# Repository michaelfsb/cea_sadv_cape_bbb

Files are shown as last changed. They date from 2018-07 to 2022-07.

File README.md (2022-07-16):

# cea_sadv_cape_bbb
Projeto no KiCad de um módulo para aquisição dados em voo realizado no projeto de Iniciação Cientifica intitulado "Modernização do Sistema de Aquisição de Dados de Voo do CEA".

cape

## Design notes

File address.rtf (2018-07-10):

I2C_2

MPU9250
68h (0)
69h (1)

4525DO - I2C_2
Definido na compra (olhar no nome)
28h, 36h, 46h, 48h ... 51h

DS3231
57h (não achei essa inf no datasheet)

CAT24C256
54h to 57h (segundo manual beaglebone)
1010 XXX Y (X - são progamaveis Y - leitura ou escrita)

I2C_1

MPU6050
68h (0)
69h (1)

BMP180
EFh (read) and EEh (write)

HMC5883
3Dh (read) and 3Ch (write)

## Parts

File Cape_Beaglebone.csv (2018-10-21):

Id | Designator | Package | Quantity | Designation | Supplier and ref
1 | NT2,NT1 | net_tie2 | 2 | Net-Tie_2
2 | C34,C33,C10,C11,C12,C13 | C_0805 | 6 | C
3 | L2,L1 | R_Axial_DIN0204_L3.6mm_D1.6mm_P7.62mm_Horizontal | 2 | I
4 | P8,P9 | Socket_BeagleBone_Black | 2 | BeagleBone_Black_Header
5 | R17,R18 | R_0603 | 2 | 0
6 | IC9 | PQFN50P300X300X100-16N | 1 | LSM303D
7 | IC10 | 16-PIN-LPCC | 1 | HMC5883L-TR
8 | IC5 | SOIC127P800X203-8N | 1 | CAT24C256WI-GT3
9 | IC11 | BMP180 | 1 | BMP180
10 | IC4,IC2 | SOIC127P600X160-16N | 2 | HX711
11 | IC6,IC7 | SOP65P640X120-16N | 2 | AD7793BRUZ
12 | IC12 | SOP50P640X120-38N | 1 | ADS8688IDBT
13 | IC13 | LGA(3X3X1.0-16L) | 1 | L3GD20H
14 | IC8 | QFN40P300X300X95-25N-D | 1 | MPU-6500
15 | IC3 | SOIC127P1032X265-16N | 1 | DS3231S
16 | U1 | 4525DO-DS...P | 1 | 4525DO-DS5AI001DP
17 | J5 | test_pad | 1 | M_WP
18 | SW1 | SW_DIP_x2_W5.08mm_Slide_Copal_CHS-A | 1 | SW_DIP_x02
19 | C24,C9 | C_0805 | 2 | 22u
20 | J11,J4,J6,J16 | JST_SH_BM06B-SRSS-TB_06x1.00mm_Straight | 4 | Conn_01x06
21 | J3 | JST_SH_BM02B-SRSS-TB_02x1.00mm_Straight | 1 | Conn_01x02
22 | J1,J2,J7,J8,J9,J10,J12,J13,J14,J15 | JST_SH_BM04B-SRSS-TB_04x1.00mm_Straight | 10 | Conn_01x04
23 | C1,C6,C18,C25,C29,C32 | C_0805 | 6 | 10u
24 | C2,C14,C31 | C_0805 | 3 | 10n
25 | C3,C4,C5,C7,C8,C15,C16,C19 | C_0805 | 8 | 0.1u
26 | C17,C27 | C_0805 | 2 | 4.7u
27 | C20,C26,C30 | C_0805 | 3 | 1u
28 | C21 | C_0805 | 1 | 0.22u
29 | C22,C23,C28 | C_0805 | 3 | 100n
30 | IC1 | QFN40P300X300X105-25N-D | 1 | MPU-9250
31 | Q1,Q2 | SOT-23 | 2 | BC807
32 | R1,R2,R3,R4,R5,R6,R13,R14 | R_0603 | 8 | R
33 | R7,R8,R9 | R_0603 | 3 | 4.7k
34 | R10,R11,R12,R15,R16 | R_0603 | 5 | 10k
35 | G*** | LOGO | 1 | LOGO

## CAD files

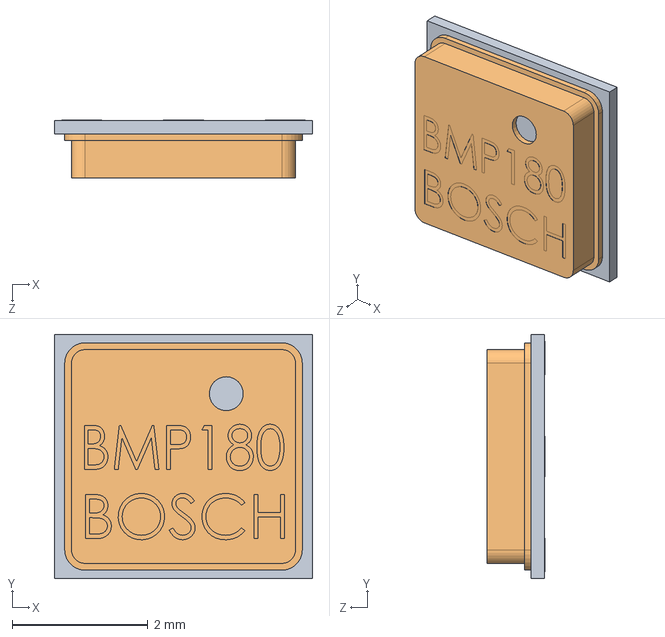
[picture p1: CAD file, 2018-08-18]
componetes/BMP180/bmp180-2.snapshot.1/BMP_180/BMP180.SLDASM
3.80 x 3.60 x 0.856 mm
PCB
Cover

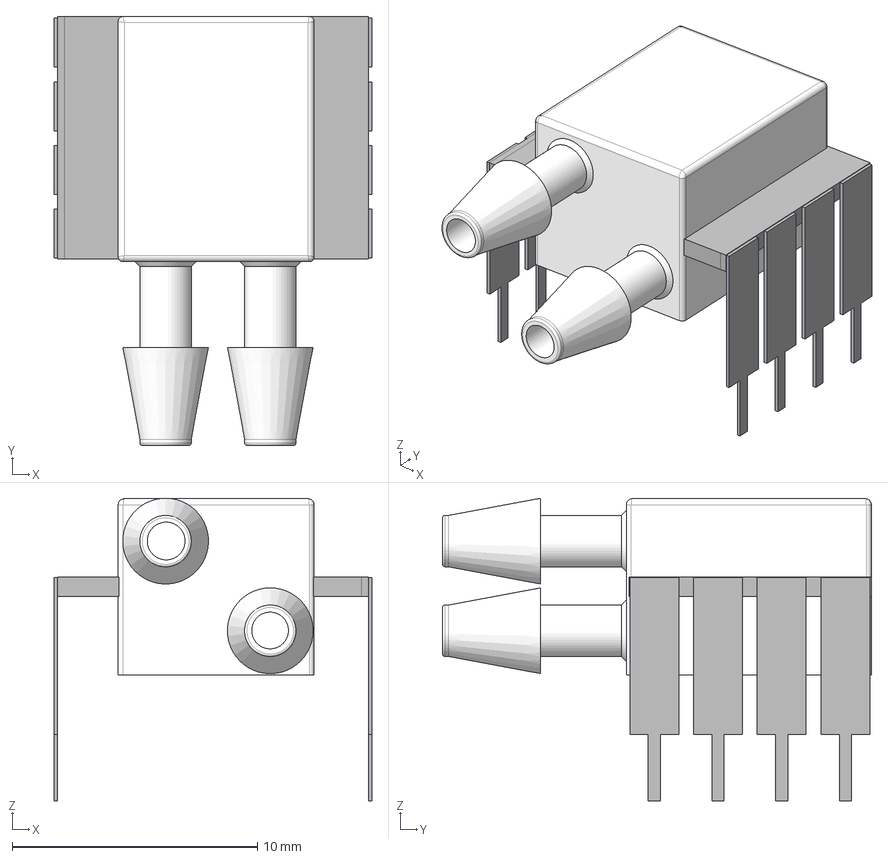
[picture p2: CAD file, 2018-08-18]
componetes/4525DO-DS5AI001DP/MS4525DO_3D_model.step
13.0 x 17.5 x 12.3 mm

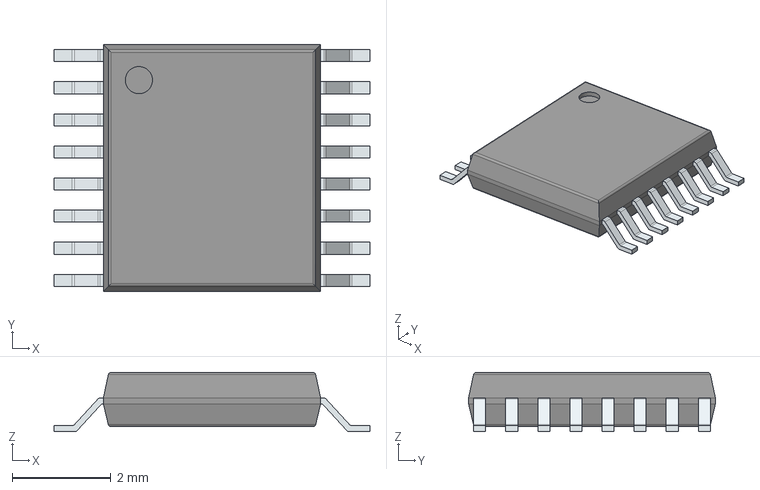
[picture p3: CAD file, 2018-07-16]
componetes/AD7793BRUZ/3D/AD7793BRUZ.stp
6.40 x 5.00 x 1.20 mm
PinsArrayLR

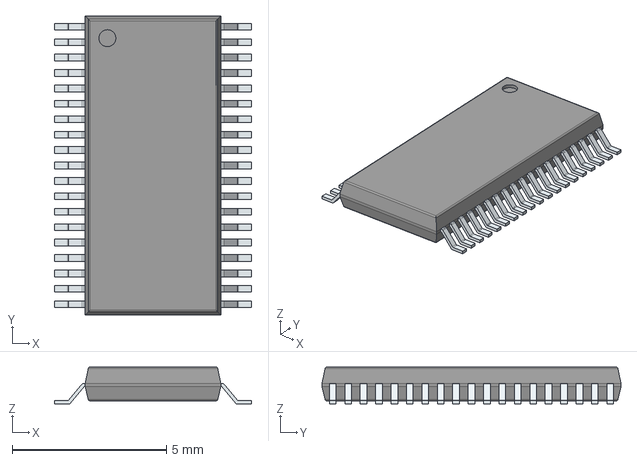
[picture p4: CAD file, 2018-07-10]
componetes/ADS8688IDBT/3D/ADS8688IDBT.stp
6.40 x 9.70 x 1.20 mm
PinsArrayLR

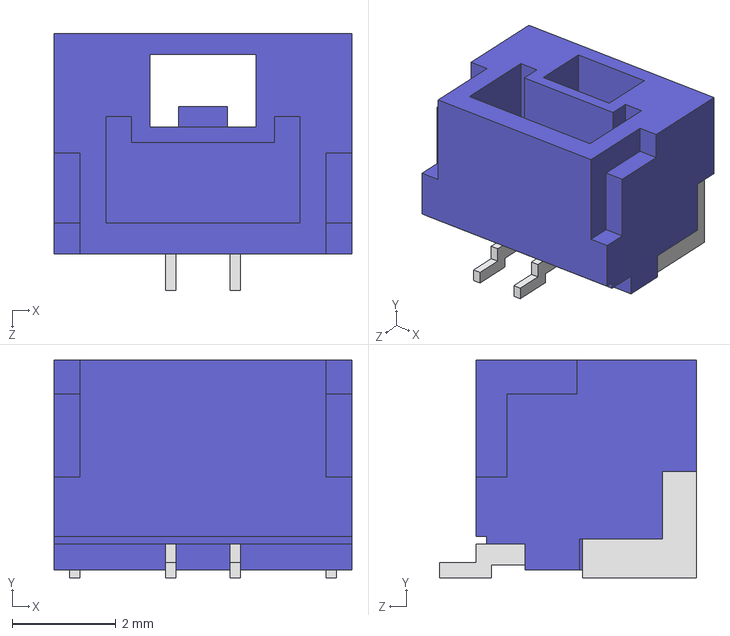
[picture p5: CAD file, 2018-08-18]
componetes/BM02B-GHS-TBT/BM02B-GHS-TBT.STEP
5.75 x 4.20 x 4.95 mm

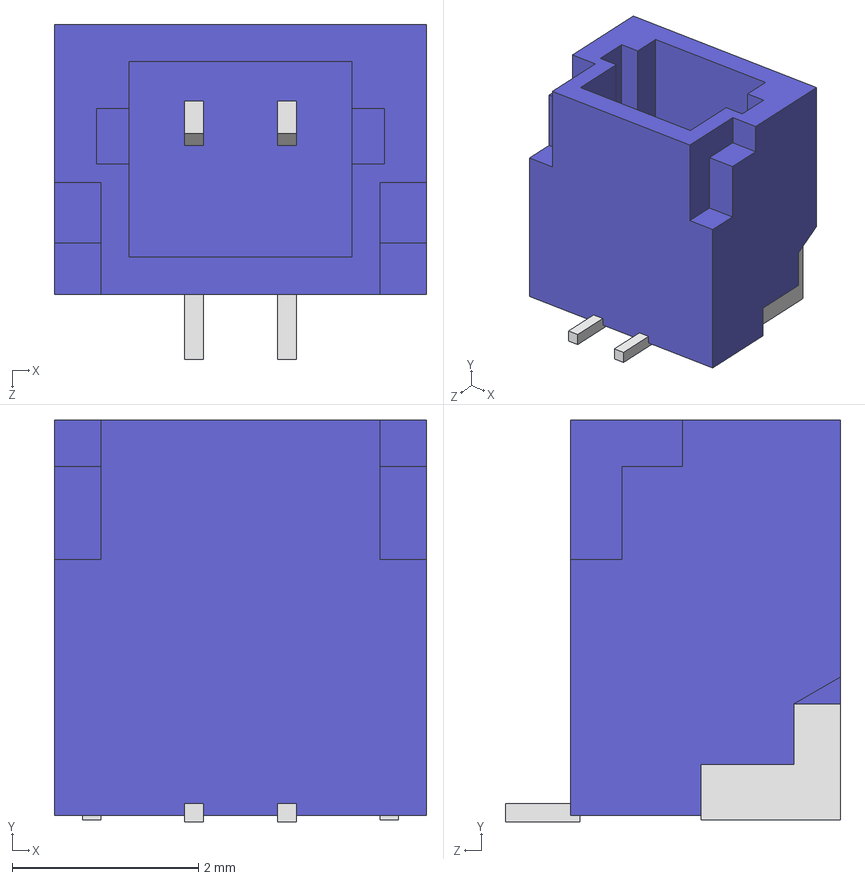
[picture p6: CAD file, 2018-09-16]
componetes/BM02B-SRSS-TB/BM02B-SRSS-TB.STEP
4.00 x 4.32 x 3.60 mm

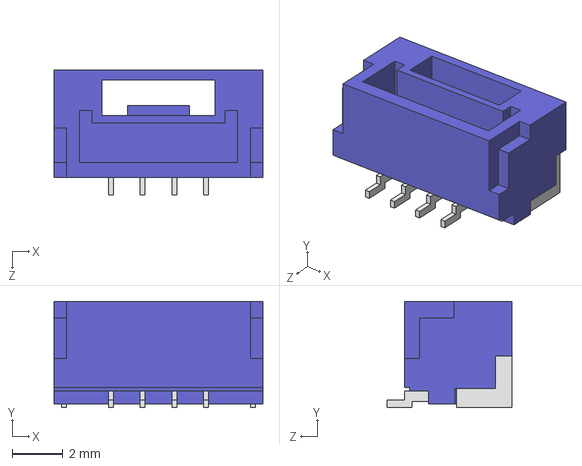
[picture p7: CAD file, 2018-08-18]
componetes/BM04B-GHS-TBT/BM04B-GHS-TBT.STEP
8.25 x 4.20 x 4.95 mm

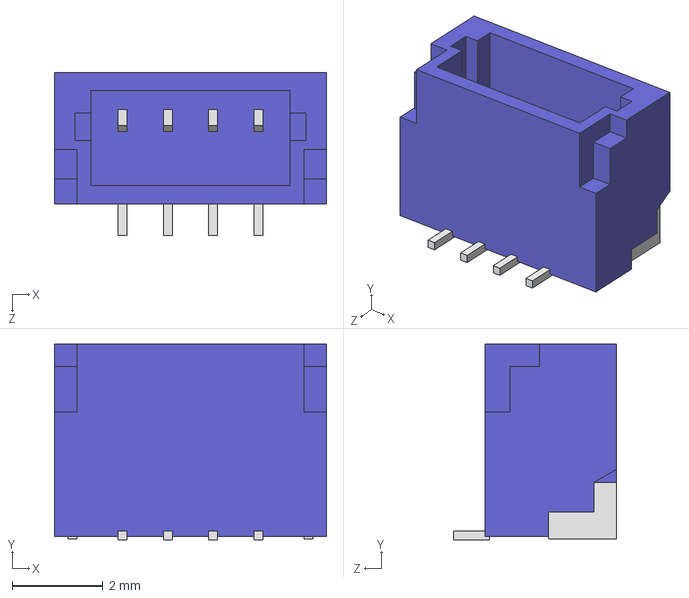
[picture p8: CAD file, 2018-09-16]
componetes/BM04B-SRSS-TB/BM04B-SRSS-TB.STEP
6.00 x 4.32 x 3.60 mm

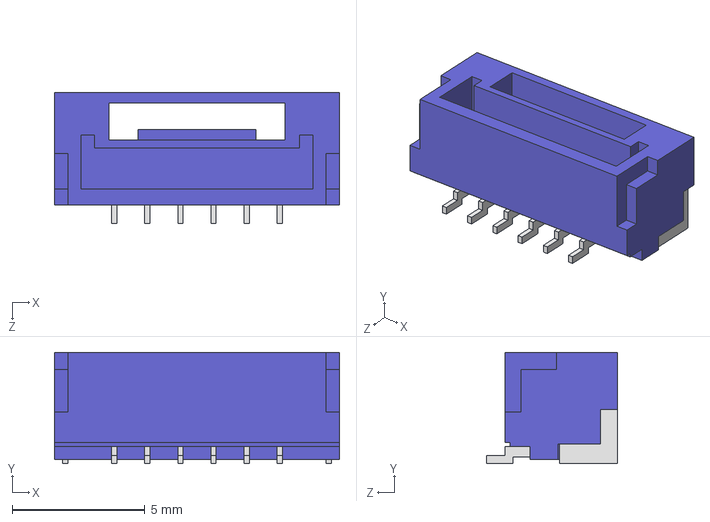
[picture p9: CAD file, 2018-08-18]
componetes/BM06B-GHS-TBT/BM06B-GHS-TBT.STEP
10.8 x 4.20 x 4.95 mm

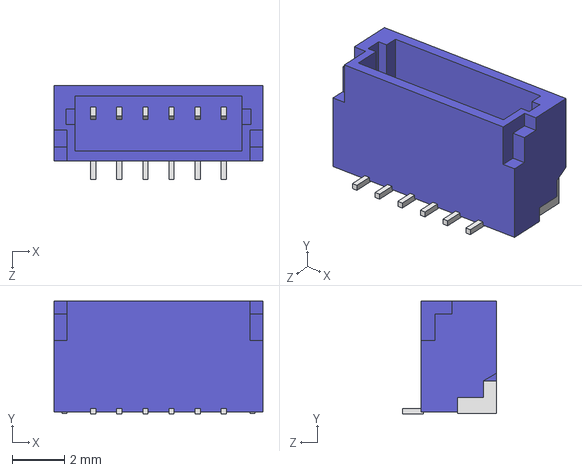
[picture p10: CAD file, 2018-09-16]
componetes/BM06B-SRSS-TB/BM06B-SRSS-TB.STEP
8.00 x 4.32 x 3.60 mm

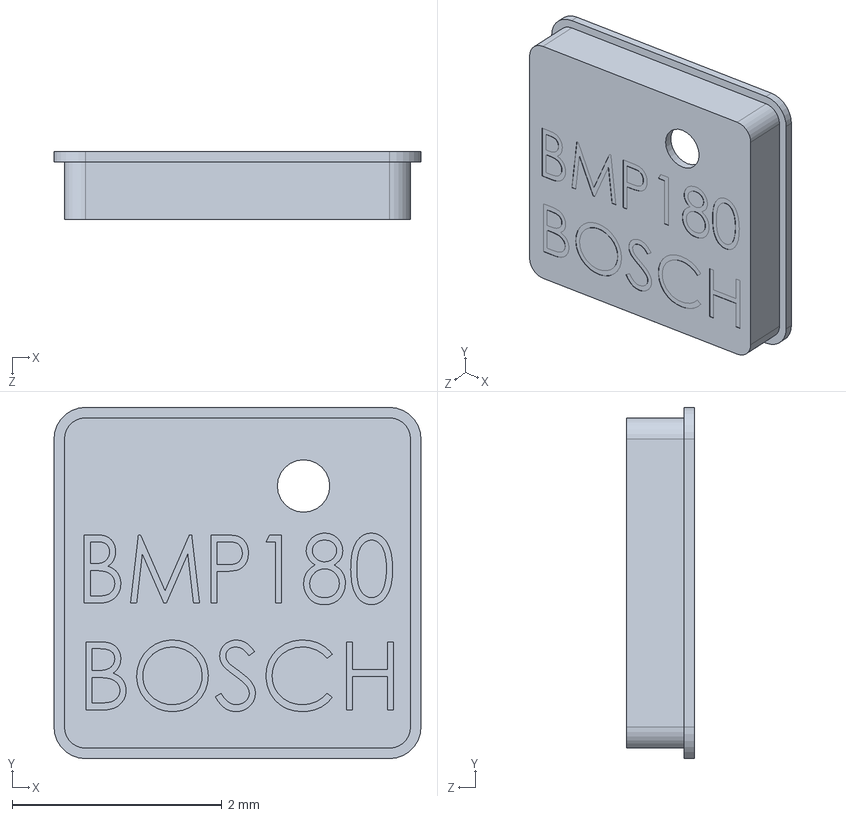
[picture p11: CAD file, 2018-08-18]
componetes/BMP180/bmp180-2.snapshot.1/BMP_180/Cover.SLDPRT
3.50 x 3.35 x 0.65 mm

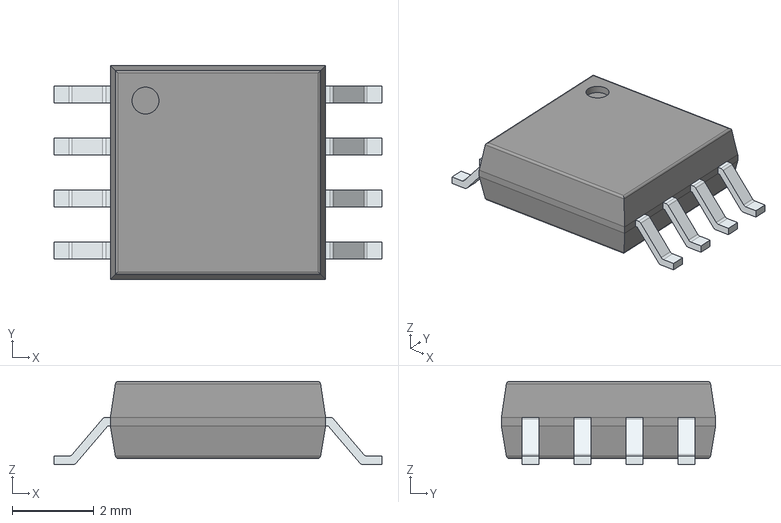
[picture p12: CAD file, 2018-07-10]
componetes/CAT24C256WI-GT3/3D/CAT24C256WI-GT3.stp
8.01 x 5.23 x 2.03 mm
PinsArrayLR

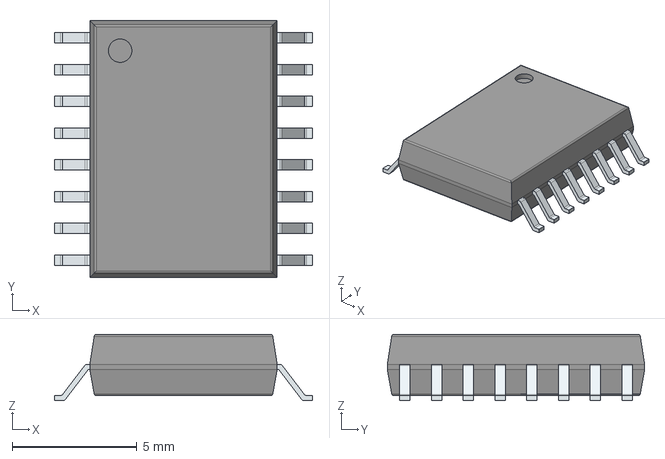
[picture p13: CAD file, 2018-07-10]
componetes/DS3231S#/3D/DS3231S#.stp
10.3 x 10.3 x 2.65 mm
PinsArrayLR

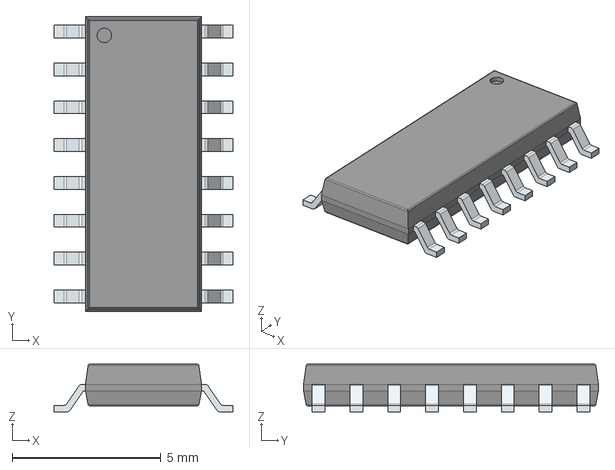
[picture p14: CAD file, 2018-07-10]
componetes/HX711/3D/HX711.stp
6.00 x 9.90 x 1.60 mm
PinsArrayLR

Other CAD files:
componetes/BMP180/bmp180_3d.step
componetes/MPU-6050/3D/MPU-6050.stp
componetes/MPU-6500/3D/mpu6500.STEP
componetes/MPU-9250/3D/MPU-9250.stp
componetes/AD7793BRUZ/3D/AD7793BRUZ.stl
componetes/ADS8688IDBT/3D/ADS8688IDBT.stl
componetes/BMP180/bmp180-2.snapshot.1/BMP_180/BMP180.IGS
componetes/BMP180/bmp180-2.snapshot.1/BMP_180/BMP180.STL
componetes/BMP180/bmp180-2.snapshot.1/BMP_180/PCB.SLDPRT
componetes/CAT24C256WI-GT3/3D/CAT24C256WI-GT3.stl
componetes/DS3231S#/3D/DS3231S#.stl
componetes/HX711/3D/HX711.stl
componetes/MPU-6050/3D/MPU-6050.stl
componetes/MPU-6500/3D/MPU-6500.stl
componetes/MPU-6500/3D/MPU-6500.stp
componetes/MPU-9250/3D/MPU-9250.stl

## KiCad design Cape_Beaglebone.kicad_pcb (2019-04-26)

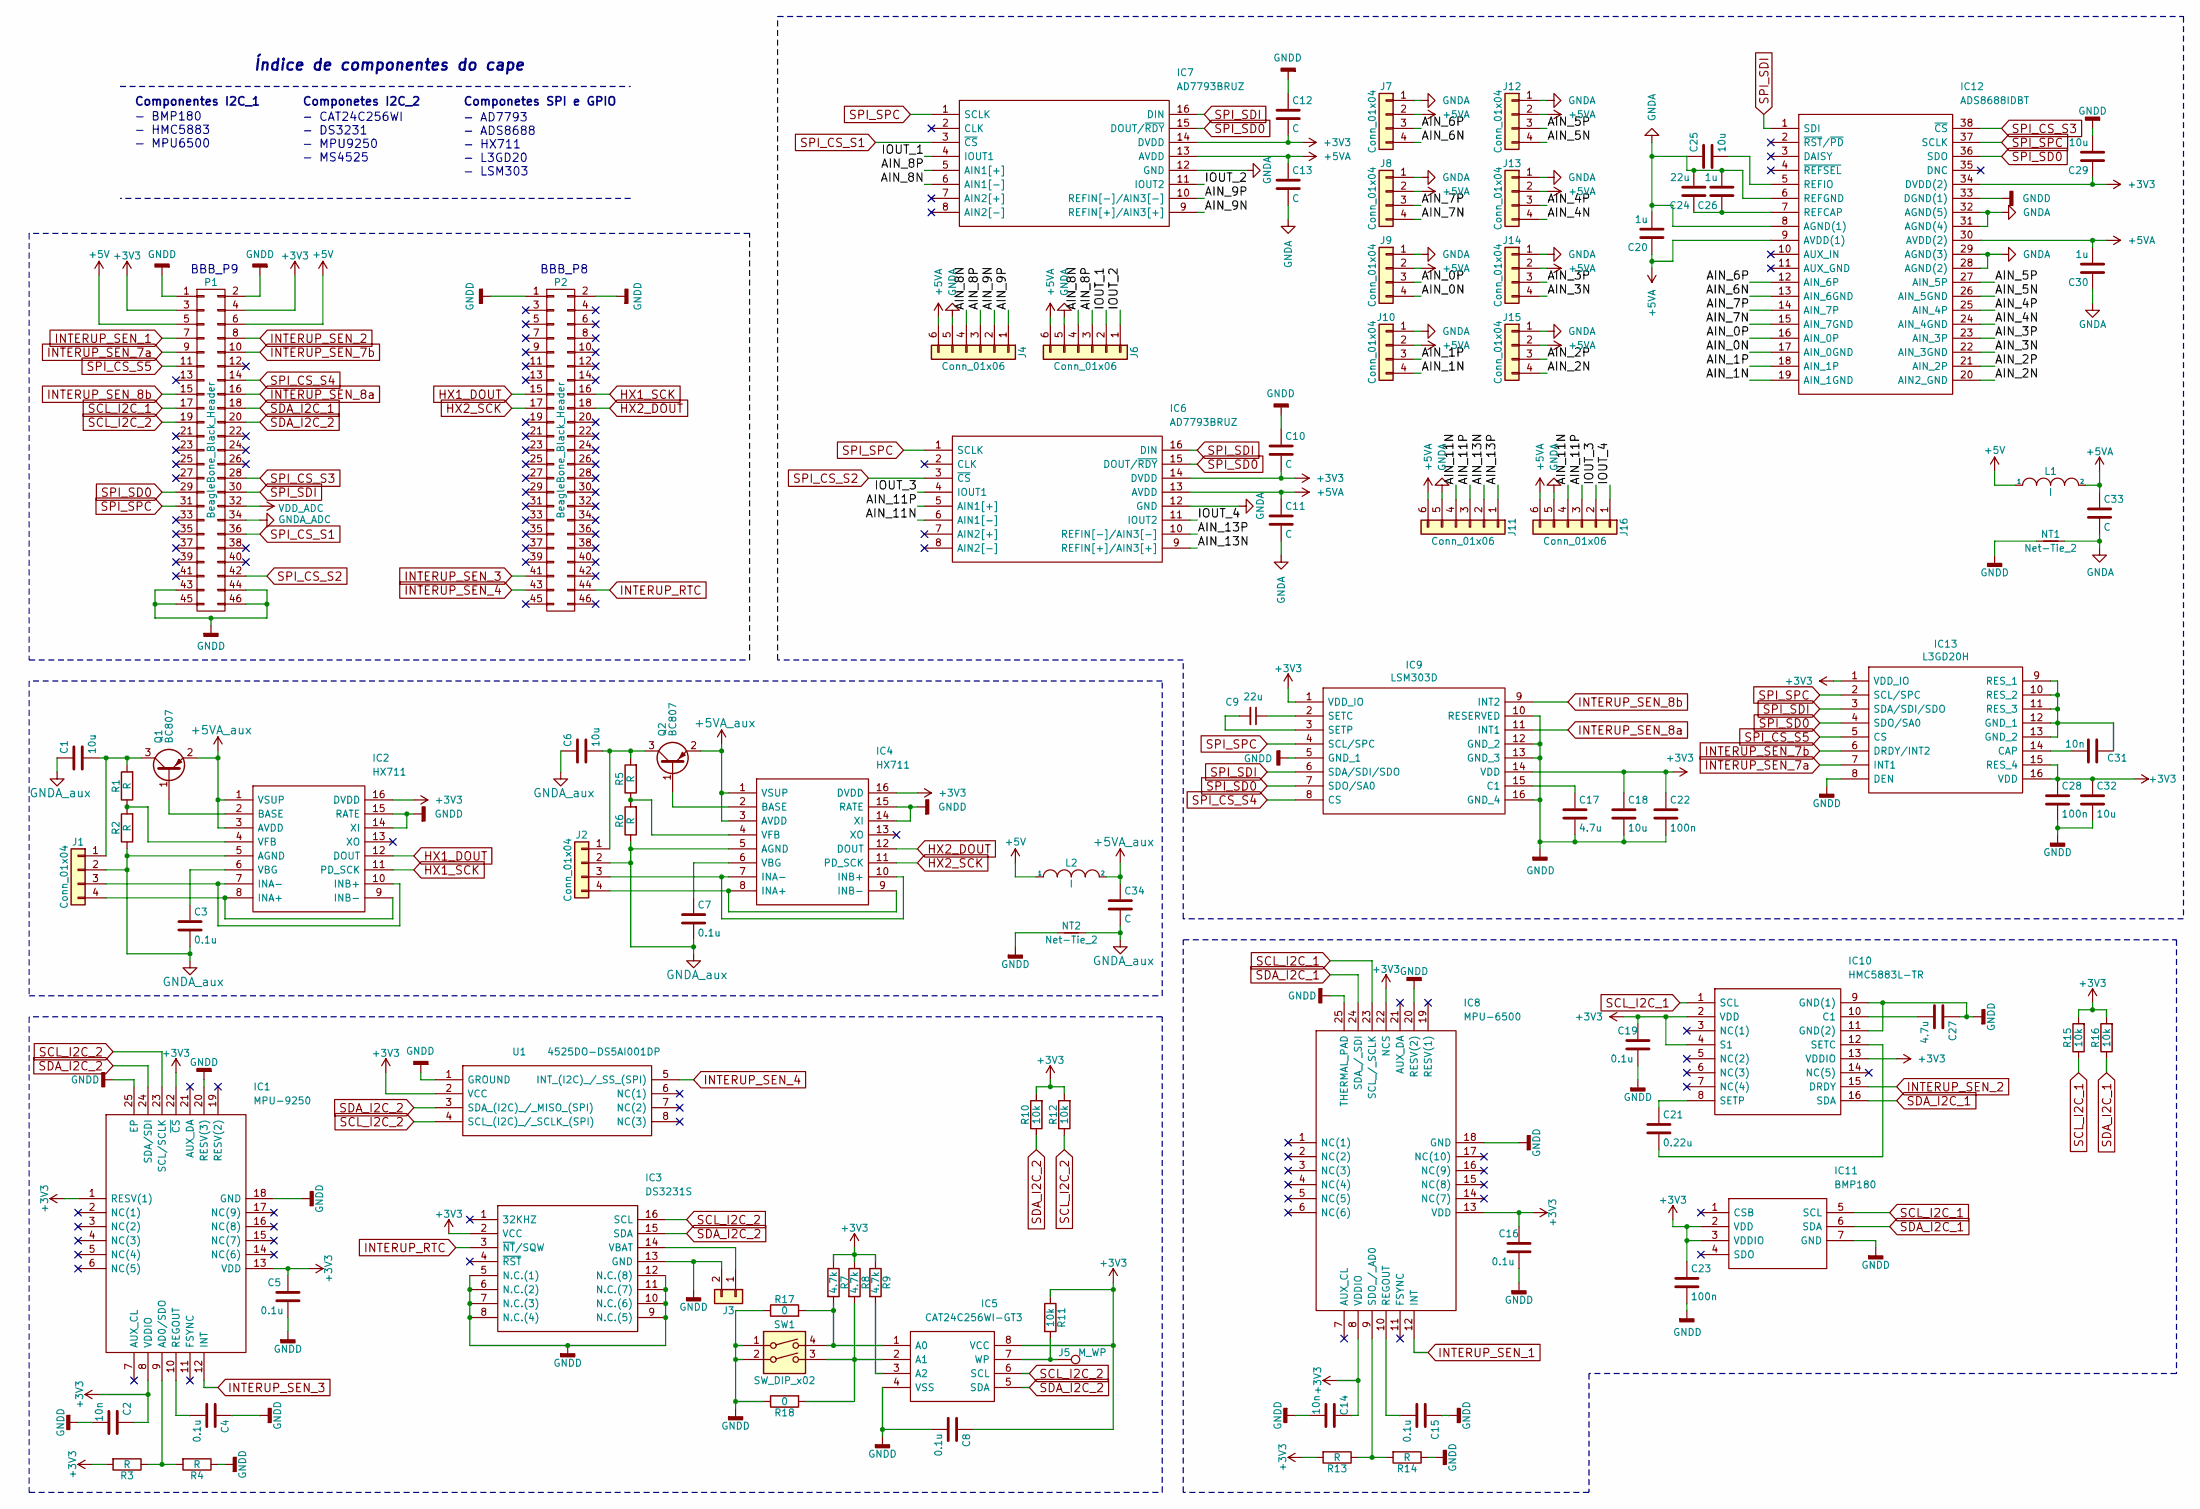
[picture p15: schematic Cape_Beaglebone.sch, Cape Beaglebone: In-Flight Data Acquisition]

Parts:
C1, C6, C18, C25, C29, C32: 10u; C_0805
C2, C14, C31: 10n; C_0805
C3, C4, C5, C7, C8, C15, C16, C19: 0.1u; C_0805
C9, C24: 22u; C_0805
C10, C11, C12, C13, C33, C34: C; C_0805
C17, C27: 4.7u; C_0805
C20, C26, C30: 1u; C_0805
C21: 0.22u; C_0805
C22, C23, C28: 100n; C_0805
IC1: MPU-9250; QFN40P300X300X105-25N-D; Manufacturer_Part_Number MPU-9250
IC2, IC4: HX711; SOIC127P600X160-16N; Manufacturer_Part_Number HX711
IC3: DS3231S; SOIC127P1032X265-16N; Manufacturer_Part_Number DS3231S#
IC5: CAT24C256WI-GT3; SOIC127P800X203-8N; Manufacturer_Part_Number CAT24C256WI-GT3
IC6, IC7: AD7793BRUZ; SOP65P640X120-16N; Manufacturer_Part_Number AD7793BRUZ
IC8: MPU-6500; QFN40P300X300X95-25N-D; Manufacturer_Part_Number MPU-6500
IC9: LSM303D; PQFN50P300X300X100-16N; Manufacturer_Part_Number LSM303D
IC10: HMC5883L-TR; 16-PIN-LPCC; Manufacturer_Part_Number HMC5883L-TR
IC11: BMP180; Manufacturer_Part_Number BMP180
IC12: ADS8688IDBT; SOP50P640X120-38N; Manufacturer_Part_Number ADS8688IDBT
IC13: L3GD20H; LGA(3X3X1.0-16L); Manufacturer_Part_Number L3GD20H
J1, J2, J7, J8, J9, J10, J12, J13, J14, J15: Conn_01x04; JST_SH_BM04B-SRSS-TB_04x1.00mm_Straight
J3: Conn_01x02; JST_SH_BM02B-SRSS-TB_02x1.00mm_Straight
J4, J6, J11, J16: Conn_01x06; JST_SH_BM06B-SRSS-TB_06x1.00mm_Straight
J5: M_WP; test_pad
L1, L2: I; R_Axial_DIN0204_L3.6mm_D1.6mm_P7.62mm_Horizontal
NT1, NT2: Net-Tie_2; net_tie2
P1, P2: BeagleBone_Black_Header; Socket_BeagleBone_Black
Q1, Q2: BC807; SOT-23
R1, R2, R3, R4, R5, R6, R13, R14: R; R_0603
R7, R8, R9: 4.7k; R_0603
R10, R11, R12, R15, R16: 10k; R_0603
R17, R18: 0; R_0603
SW1: SW_DIP_x02; SW_DIP_x2_W5.08mm_Slide_Copal_CHS-A
U1: 4525DO-DS5AI001DP; 4525DO-DS...P; Manufacturer_Part_Number 4525DO-DS5AI001DP

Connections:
+3V3: C2.1, C5.1, C8.1, C10.2, C12.2, C14.1, C16.1, C18.1, C19.1, C22.1, C23.1, C28.1, C29.1, C32.1, IC1.1 (RESV(1)), IC1.8 (VDDIO), IC1.13 (VDD), IC1.22 (~CS), IC2.16 (DVDD), IC3.2 (VCC), IC4.16 (DVDD), IC5.8 (VCC), IC6.14 (DVDD), IC7.14 (DVDD), IC8.8 (VDDIO), IC8.13 (VDD), IC8.22 (NCS), IC9.1 (VDD_IO), IC9.14 (VDD), IC10.2 (VDD), IC10.4 (S1), IC10.13 (VDDIO), IC11.2 (VDD), IC11.3 (VDDIO), IC12.34 (DVDD(2)), IC13.1 (VDD_IO), IC13.15 (RES_4), IC13.16 (VDD), P1.3, P1.4, R3.2, R7.1, R8.1, R9.1, R10.2, R11.1, R12.2, R13.2, R15.2, R16.2, U1.2 (VCC); also elsewhere on the board
+5V: L1.1, L2.1, P1.5, P1.6; also elsewhere on the board
+5VA: C11.1, C13.1, C20.1, C30.2, C33.1, IC6.13 (AVDD), IC7.13 (AVDD), IC12.9 (AVDD(1)), IC12.30 (AVDD(2)), J4.6, J6.6, J7.2, J8.2, J9.2, J10.2, J11.6, J12.2, J13.2, J14.2, J15.2, J16.6, L1.2
+5VA_aux: C34.1, IC2.1 (VSUP), IC2.3 (AVDD), IC4.1 (VSUP), IC4.3 (AVDD), L2.2, Q1.2 (E), Q2.2 (E)
/AIN_0N: IC12.17 (AIN_0GND), J9.4
/AIN_0P: IC12.16 (AIN_0P), J9.3
/AIN_1N: IC12.19 (AIN_1GND), J10.4
/AIN_1P: IC12.18 (AIN_1P), J10.3
/AIN_2N: IC12.20 (AIN2_GND), J15.4
/AIN_2P: IC12.21 (AIN_2P), J15.3
/AIN_3N: IC12.22 (AIN_3GND), J14.4
/AIN_3P: IC12.23 (AIN_3P), J14.3
/AIN_4N: IC12.24 (AIN_4GND), J13.4
/AIN_4P: IC12.25 (AIN_4P), J13.3
/AIN_5N: IC12.26 (AIN_5GND), J12.4
/AIN_5P: IC12.27 (AIN_5P), J12.3
/AIN_6N: IC12.13 (AIN_6GND), J7.4
/AIN_6P: IC12.12 (AIN_6P), J7.3
/AIN_7N: IC12.15 (AIN_7GND), J8.4
/AIN_7P: IC12.14 (AIN_7P), J8.3
/AIN_8N: IC7.6 (AIN1[-]), J4.4, J6.4
/AIN_8P: IC7.5 (AIN1[+]), J4.3, J6.3
/AIN_9N: IC7.9 (REFIN[+]/AIN3[+]), J4.2
/AIN_9P: IC7.10 (REFIN[-]/AIN3[-]), J4.1
/AIN_11N: IC6.6 (AIN1[-]), J11.4, J16.4
/AIN_11P: IC6.5 (AIN1[+]), J11.3, J16.3
/AIN_13N: IC6.9 (REFIN[+]/AIN3[+]), J11.2
/AIN_13P: IC6.10 (REFIN[-]/AIN3[-]), J11.1
/IOUT_1: IC7.4 (IOUT1), J6.2
/IOUT_2: IC7.11 (IOUT2), J6.1
/IOUT_3: IC6.4 (IOUT1), J16.2
/IOUT_4: IC6.11 (IOUT2), J16.1
GNDA: C11.2, C13.2, C20.2, C24.2, C25.1, C26.2, C30.1, C33.2, IC6.12 (GND), IC7.12 (GND), IC12.6 (REFGND), IC12.8 (AGND(1)), IC12.28 (AGND(2)), IC12.29 (AGND(3)), IC12.31 (AGND(4)), IC12.32 (AGND(5)), J4.5, J6.5, J7.1, J8.1, J9.1, J10.1, J11.5, J12.1, J13.1, J14.1, J15.1, J16.5, NT1.2
GNDA_aux: C1.1, C3.2, C6.1, C7.2, C34.2, IC2.5 (AGND), IC4.5 (AGND), J1.2, J2.2, NT2.2, R2.1, R6.1
GNDD: C2.2, C4.1, C5.2, C8.2, C10.1, C12.1, C14.2, C15.1, C16.2, C17.2, C18.2, C19.2, C22.2, C23.2, C27.1, C28.2, C29.2, C32.2, IC1.18 (GND), IC1.20 (RESV(3)), IC1.25 (EP), IC2.14 (XI), IC2.15 (RATE), IC3.5 (N.C.(1)), IC3.6 (N.C.(2)), IC3.7 (N.C.(3)), IC3.8 (N.C.(4)), IC3.9 (N.C.(5)), IC3.10 (N.C.(6)), IC3.11 (N.C.(7)), IC3.12 (N.C.(8)), IC3.13 (GND), IC4.14 (XI), IC4.15 (RATE), IC5.4 (VSS), IC8.18 (GND), IC8.20 (RESV(2)), IC8.25 (THERMAL_PAD), IC9.5 (GND_1), IC9.10 (RESERVED), IC9.12 (GND_2), IC9.13 (GND_3), IC9.16 (GND_4), IC10.9 (GND(1)), IC10.11 (GND(2)), IC11.7 (GND), IC12.33 (DGND(1)), IC13.8 (DEN), J3.2, NT1.1, NT2.1, P1.1, P1.2, P1.43, P1.44, P1.45, P1.46, P2.1, P2.2, R4.1, R14.1, R17.1, R18.1, SW1.1, SW1.2, U1.1 (GROUND); also elsewhere on the board
HX1_DOUT: IC2.12 (DOUT), P2.15; also elsewhere on the board
HX1_SCK: IC2.11 (PD_SCK), P2.16; also elsewhere on the board
HX2_DOUT: IC4.12 (DOUT), P2.18; also elsewhere on the board
HX2_SCK: IC4.11 (PD_SCK), P2.17; also elsewhere on the board
INTERUP_RTC: IC3.3 (~NT~/SQW), P2.44; also elsewhere on the board
INTERUP_SEN_1: IC8.12 (INT), P1.7; also elsewhere on the board
INTERUP_SEN_2: IC10.15 (DRDY), P1.8; also elsewhere on the board
INTERUP_SEN_3: IC1.12 (INT), P2.41; also elsewhere on the board
INTERUP_SEN_4: P2.43, U1.5 (INT_(I2C)_/_SS_(SPI)); also elsewhere on the board
INTERUP_SEN_7a: IC13.7 (INT1), P1.9; also elsewhere on the board
INTERUP_SEN_7b: IC13.6 (DRDY/INT2), P1.10; also elsewhere on the board
INTERUP_SEN_8a: IC9.11 (INT1), P1.16; also elsewhere on the board
INTERUP_SEN_8b: IC9.9 (INT2), P1.15; also elsewhere on the board
unnamed: C1.2, J1.1, Q1.3 (C), R1.2
unnamed: C3.1, IC2.6 (VBG)
unnamed: C4.2, IC1.10 (REGOUT)
unnamed: C6.2, J2.1, Q2.3 (C), R5.2
unnamed: C7.1, IC4.6 (VBG)
unnamed: C9.1, IC9.2 (SETC)
unnamed: C9.2, IC9.3 (SETP)
unnamed: C15.2, IC8.10 (REGOUT)
unnamed: C17.1, IC9.15 (C1)
unnamed: C21.1, IC10.8 (SETP)
unnamed: C21.2, IC10.12 (SETC)
unnamed: C24.1, C26.1, IC12.7 (REFCAP)
unnamed: C25.2, IC12.5 (REFIO)
unnamed: C27.2, IC10.10 (C1)
unnamed: C31.1, IC13.9 (RES_1), IC13.10 (RES_2), IC13.11 (RES_3), IC13.12 (GND_1), IC13.13 (GND_2)
unnamed: C31.2, IC13.14 (CAP)
unnamed: IC1.9 (AD0/SDO), R3.1, R4.2
unnamed: IC2.2 (BASE), Q1.1 (B)
unnamed: IC2.4 (VFB), R1.1, R2.2
unnamed: IC2.8 (INA+), IC2.9 (INB-), J1.4
unnamed: IC2.7 (INA-), IC2.10 (INB+), J1.3
unnamed: IC3.14 (VBAT), J3.1
unnamed: IC4.2 (BASE), Q2.1 (B)
unnamed: IC4.4 (VFB), R5.1, R6.2
unnamed: IC4.8 (INA+), IC4.9 (INB-), J2.4
unnamed: IC4.7 (INA-), IC4.10 (INB+), J2.3
unnamed: IC5.1 (A0), R7.2, R17.2, SW1.4
unnamed: IC5.2 (A1), R8.2, R18.2, SW1.3
unnamed: IC5.3 (A2), R9.2
unnamed: IC5.7 (WP), J5.1, R11.2
unnamed: IC8.9 (SDO_/_AD0), R13.1, R14.2
SCL_I2C_1: IC8.23 (SCL_/_SCLK), IC10.1 (SCL), IC11.5 (SCL), P1.17, R15.1; also elsewhere on the board
SCL_I2C_2: IC1.23 (SCL/SCLK), IC3.16 (SCL), IC5.6 (SCL), P1.19, R12.1, U1.4 (SCL_(I2C)_/_SCLK_(SPI)); also elsewhere on the board
SDA_I2C_1: IC8.24 (SDA_/_SDI), IC10.16 (SDA), IC11.6 (SDA), P1.18, R16.1; also elsewhere on the board
SDA_I2C_2: IC1.24 (SDA/SDI), IC3.15 (SDA), IC5.5 (SDA), P1.20, R10.1, U1.3 (SDA_(I2C)_/_MISO_(SPI)); also elsewhere on the board
SPI_CS_S1: IC7.3 (~CS), P1.36; also elsewhere on the board
SPI_CS_S2: IC6.3 (~CS), P1.42; also elsewhere on the board
SPI_CS_S3: IC12.38 (~CS), P1.28; also elsewhere on the board
SPI_CS_S4: IC9.8 (CS), P1.14; also elsewhere on the board
SPI_CS_S5: IC13.5 (CS), P1.11; also elsewhere on the board
SPI_SD0: IC6.15 (DOUT/~RDY), IC7.15 (DOUT/~RDY), IC9.7 (SDO/SA0), IC12.36 (SDO), IC13.4 (SDO/SA0), P1.29; also elsewhere on the board
SPI_SDI: IC6.16 (DIN), IC7.16 (DIN), IC9.6 (SDA/SDI/SDO), IC12.1 (SDI), IC13.3 (SDA/SDI/SDO), P1.30; also elsewhere on the board
SPI_SPC: IC6.1 (SCLK), IC7.1 (SCLK), IC9.4 (SCL/SPC), IC12.37 (SCLK), IC13.2 (SCL/SPC), P1.31; also elsewhere on the board

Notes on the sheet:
- BMP180 - HMC5883 - MPU6500
Componentes I2C_1
Componetes I2C_2
- CAT24C256WI - DS3231 - MPU9250 - MS4525
Componetes SPI e GPIO
- AD7793 - ADS8688 - HX711 - L3GD20 - LSM303
Índice de componentes do cape
BBB_P8
BBB_P9

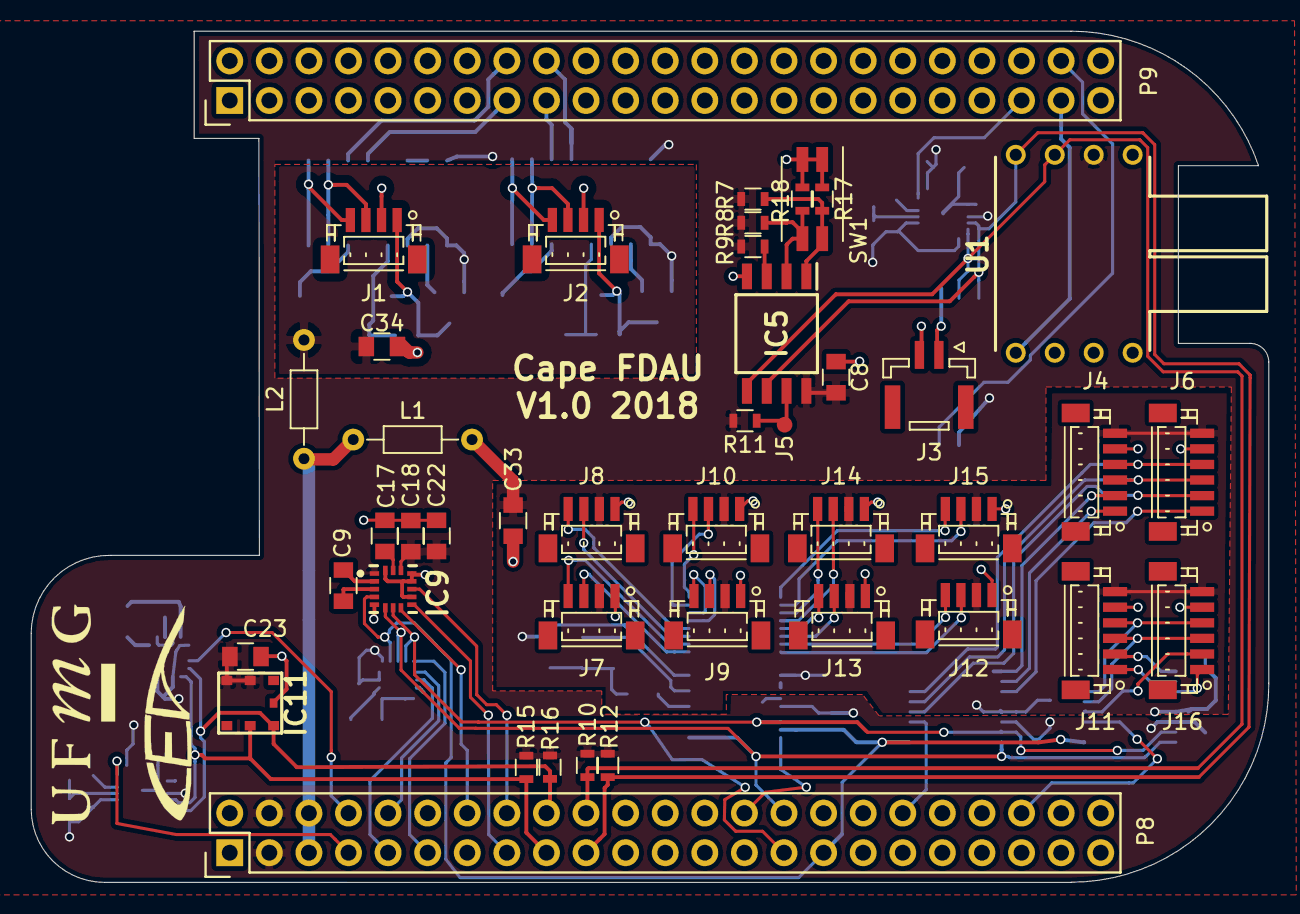
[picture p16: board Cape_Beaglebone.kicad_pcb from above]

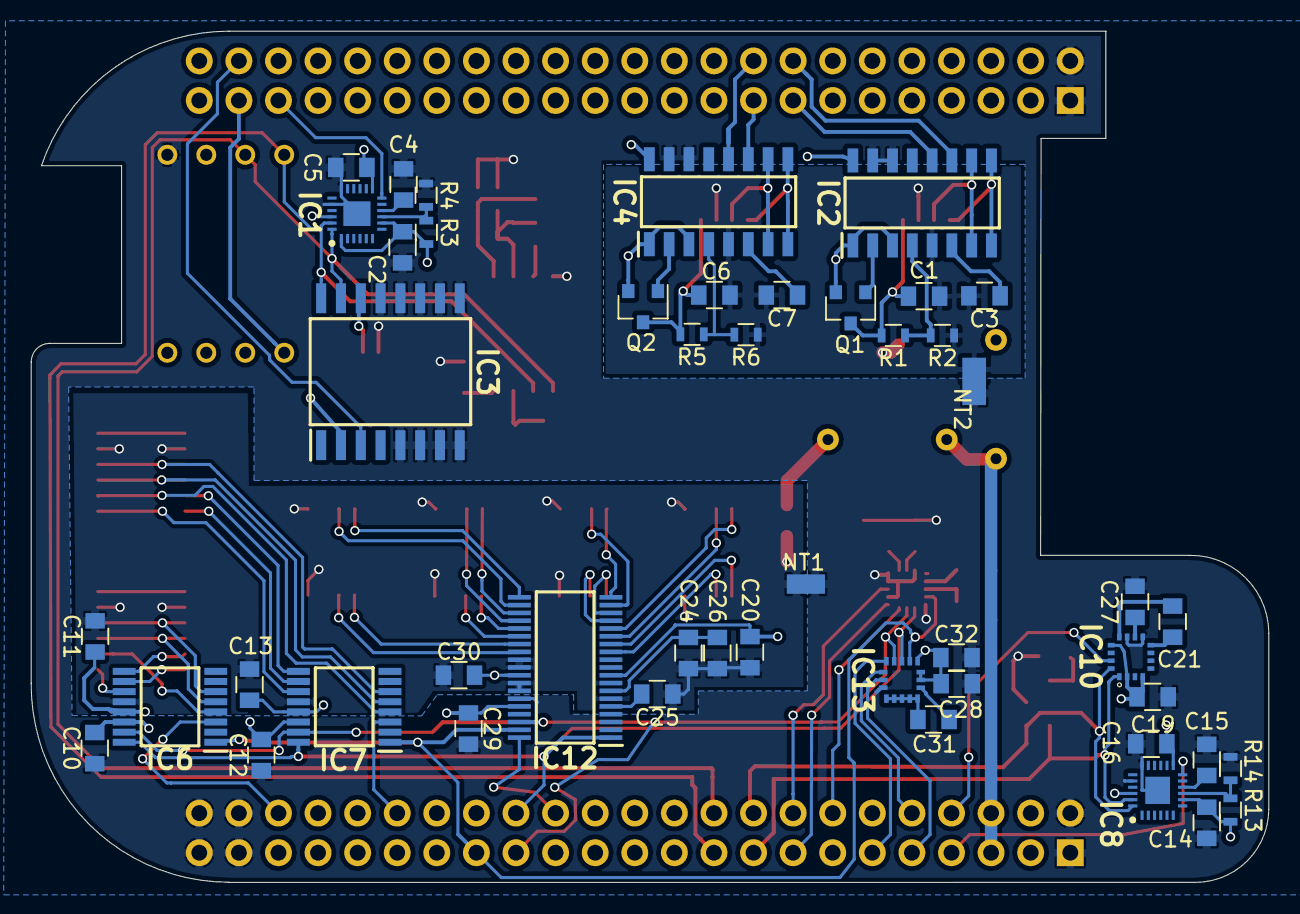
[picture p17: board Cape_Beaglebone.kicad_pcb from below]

Board: 2 copper layers, 79.4 x 54.6 mm, 91 parts (48 on the bottom side), 91 nets.

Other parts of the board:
P8, P9: BeagleBone_Black_Header; Socket_BeagleBone_Black

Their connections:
+3V3: P8.3, P8.4; also elsewhere on the board
+5V: P8.5, P8.6; also elsewhere on the board
GNDD: P8.1, P8.2, P8.43, P8.44, P8.45, P8.46, P9.1, P9.2; also elsewhere on the board
HX1_DOUT: P9.15; also elsewhere on the board
HX1_SCK: P9.16; also elsewhere on the board
HX2_DOUT: P9.18; also elsewhere on the board
HX2_SCK: P9.17; also elsewhere on the board
INTERUP_RTC: P9.44; also elsewhere on the board
INTERUP_SEN_1: P8.7; also elsewhere on the board
INTERUP_SEN_2: P8.8; also elsewhere on the board
INTERUP_SEN_3: P9.41; also elsewhere on the board
INTERUP_SEN_4: P9.43; also elsewhere on the board
INTERUP_SEN_7a: P8.9; also elsewhere on the board
INTERUP_SEN_7b: P8.10; also elsewhere on the board
INTERUP_SEN_8a: P8.16; also elsewhere on the board
INTERUP_SEN_8b: P8.15; also elsewhere on the board
SCL_I2C_1: P8.17; also elsewhere on the board
SCL_I2C_2: P8.19; also elsewhere on the board
SDA_I2C_1: P8.18; also elsewhere on the board
SDA_I2C_2: P8.20; also elsewhere on the board
SPI_CS_S1: P8.36; also elsewhere on the board
SPI_CS_S2: P8.42; also elsewhere on the board
SPI_CS_S3: P8.28; also elsewhere on the board
SPI_CS_S4: P8.14; also elsewhere on the board
SPI_CS_S5: P8.11; also elsewhere on the board
SPI_SD0: P8.29; also elsewhere on the board
SPI_SDI: P8.30; also elsewhere on the board
SPI_SPC: P8.31; also elsewhere on the board

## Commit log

2018-07-29 mfsb_29_07_18
    Primeira tentativa do layout
    [Cape_Beaglebone.kicad_pcb, Cape_Beaglebone.sch]
2018-07-31 Revisões no esquemático do RTC.
    [Cape_Beaglebone.sch]
2018-07-31 Revisões no esquemático do HX711.
    [Cape_Beaglebone.sch]
2018-07-31 Revisões no esquemático do AD7793.
    [Cape_Beaglebone.sch]
2018-07-31 Revisões no esquemático do ADS8688.
    [Cape_Beaglebone.sch]
2018-08-18 Layout com SJT GH
    Layout quase finalizado usando os conectores SJT GH de 1,25 mm
    [BM02B-GHS-TBT.STEP, BM04B-GHS-TBT.STEP, BM06B-GHS-TBT.STEP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]
2018-09-16 Final V1.0
    Primeria versão final sem revisão
    [BM02B-SRSS-TB.STEP, BM04B-SRSS-TB.STEP, BM06B-SRSS-TB.STEP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]
2018-09-28 Corte para mangeira
    Alteração para facilitar a colocação de magueira no sensor de pressão
    [Cape_Beaglebone.kicad_pcb, Cape_Beaglebone.sch]
2018-10-21 GNDA
    Correções no ground
    [Cape_Beaglebone.csv, Cape_Beaglebone.kicad_pcb]
2018-11-05 Conector bateiira RTC
    Troca do conector da bateria do RTC de JSH SH para o JST GH. Pois não tinha o SH disponivel para comprar.
    [Cape_Beaglebone-B.Cu.gbr, Cape_Beaglebone-B.Mask.gbr, Cape_Beaglebone-B.SilkS.gbr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]
2018-11-05 Arquivos Gerber
    Arquivos Gerber
2019-04-26 Atualizando para Kicad 5.1.0
    [Cape_Beaglebone.kicad_pcb, Cape_Beaglebone.sch]
2019-04-27 Corrigindo referências a bibliotecas de símbolos.
2019-04-27 Corrigi erro alias inexistente para VDD_ADC.
    [Cape_Beaglebone.sch]
